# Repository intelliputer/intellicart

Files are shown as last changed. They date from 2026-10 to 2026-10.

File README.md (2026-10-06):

## Intellicart

Intellicart is a flash-cartridge project for the Mattel Intellivision. It loads Intellivision program images from a micro SD card and presents a small OLED/button interface for selecting and starting them on original hardware.

This repository brings together the hardware design, fabrication package, firmware, user documentation, and a small reverse-engineering workspace for experimenting with human--agent gameplay.

## Repository layout

| Path | Contents |
| --- | --- |
| [`board/project/`](board/project/) | KiCad schematic, PCB, project configuration, routing, and BOM files. |
| [`board/gerbers/`](board/gerbers/) | Generated fabrication deliverables: Gerbers, drill files, drill maps, and the Gerber job file. |
| [`development/arduino/`](development/arduino/) | Cartridge-controller firmware source. |
| [`development/checkers-disassembly/`](development/checkers-disassembly/) | CP1610 disassembly and analysis workspace for the bundled Checkers ROM. |
| [`manual/`](manual/) | Intellicart user manual as LaTeX source, diagram asset, and compiled PDF. |
| [`rom/`](rom/) | ROM images used for development and research. |
| [`images/`](images/) | Project imagery. |

## Hardware

The KiCad project is [`board/project/intellicart.kicad_pro`](board/project/intellicart.kicad_pro). For manufacturing, use the complete, matching output set in [`board/gerbers/`](board/gerbers/). KiCad is configured to place newly plotted outputs there (`../gerbers/` relative to the project directory).

## User manual

The editable source is [`manual/UserManual.tex`](manual/UserManual.tex). To rebuild the PDF:

```bash
cd manual
latexmk -pdf UserManual.tex
```

## Checkers human--agent gameplay research

[`rom/Checkers (1979) (Mattel).int`](rom/Checkers%20(1979)%20(Mattel).int) is an 8 KiB CP1610 ROM mapped at `$5000`--`$5FFF`. Its generated assembly listing lives in [`development/checkers-disassembly/checkers.asm`](development/checkers-disassembly/checkers.asm).

To regenerate that listing, place the SDK1600 repository adjacent to this one and run:

```bash
development/checkers-disassembly/build-disassembly.sh
```

The script builds a temporary native `dasm1600` executable from `../sdk1600/src/dasm/dasm1600.c`, so it does not add a compiled tool to this repository. The original ROM remains unmodified.

## Licensing and ROMs

The hardware and project files are provided under the repository's [license](LICENSE). ROM images may be subject to their own rights; use and distribute them only where you have the appropriate authorization.

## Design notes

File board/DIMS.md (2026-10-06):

## 44-pin edge connector 

The geometry of the edge connector is contained in the following.

| Feature | Dimension | Status / Notes |
|---|---:|---|
| Total electrical contacts | 44 | 22 contacts on each side of the cartridge PCB |
| Contacts per PCB side | 22 | One row of edge fingers per PCB surface |
| Contact pitch | 2.54 mm (0.100 in) | Cartridge contact spacing |
| Number of pitch intervals | 21 | 22 contacts create 21 intervals |
| First-to-last terminal center span | 53.34 mm (2.100 in) | 21 × 2.54 mm; agrees with the measured ~53.4 mm |
| Measured terminal-to-terminal span | ~53.4 mm | User measurement; presumably center-to-center |
| Overall contact-array width | Approximately 58 mm | Depends on terminal width and end margins |
| Cartridge PCB thickness | Approximately 1.6 mm (0.062 in) | Verify against the original cartridge PCB |
| Replacement connector solder-tail pitch | May be 3.96 mm (0.156 in) | Connector-specific; not the cartridge contact pitch |

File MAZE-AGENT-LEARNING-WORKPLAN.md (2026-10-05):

# Maze Agent Learning Workplan

## Purpose

Build agents that navigate finite mazes from local observations, and evaluate
them against a deterministic reference procedure. A completed run alone is not
evidence of a general solution: the input domain, available memory,
transition rules, and halting conditions must all be explicit.

This plan is based on Chapter 3, “An Algorithm for Finding Paths in a
Labyrinth,” in B. A. Trakhtenbrot’s *Algorithms and Automatic Computing
Machines*, and the accompanying project notes in
`references/trakhtenbrot-algorithms-and-automatic-computing-machines-notes.md`.

## 1. Define the Maze Contract

- Represent a maze as a finite, undirected graph of junctions and corridors.
- Record a cyclic ordering of exits at each junction, a start junction, and a
  target junction.
- Define observations, legal actions, available agent memory, terminal states,
  and a fixed tie-break convention. For example: choose the first unvisited
  exit clockwise from the corridor used to enter the junction.
- Convert procedural layouts, including Entombed-generated layouts, to this
  graph representation only after validating their entrances, exits, and
  connectivity.

**Deliverable:** a versioned `Maze` schema and deterministic, seeded map
generation.

## 2. Build the Reference Solver

Implement the Chapter 3 Theseus procedure:

- Mark corridors as untraversed (green), active path (yellow), or exhausted
  (red).
- At each junction, apply this priority order: target, loop, untraversed
  corridor, origin, then backtrack.
- Never traverse a red corridor.
- Emit a trace for every step: observation, controller state, selected
  corridor, marking change, position, and halt reason.

**Acceptance criteria:** the solver halts on every finite fixture, never
traverses a red corridor, and its yellow corridors always form the current
simple path from the start to the agent.

## 3. Create a Benchmark Curriculum

Introduce structural difficulty gradually:

1. Trees and single-route mazes.
2. Dead ends and unreachable targets.
3. Loops and several routes to the target.
4. Larger maps with varying cyclic exit order.
5. Held-out procedural and Entombed-derived layouts.

For each benchmark, preserve the seed, graph, reference trace, reachability
result, path length, corridor-traversal count, and expected halt reason.

## 4. Separate Learning Tracks

Keep three experiments distinct:

- **Imitation learning:** reproduce the reference controller from local
  observations and memory.
- **Reinforcement learning:** learn from reward; label this as learned and
  potentially stochastic behavior rather than a deterministic algorithm.
- **Memory ablations:** compare reactive agents, bounded recurrent memory, and
  agents with explicit corridor-marking memory.

This identifies which memory model is necessary, instead of measuring only
whether an agent eventually succeeds.

## 5. Evaluate Behavior, Not Only Completion

Measure:

- Reachability accuracy and false “unreachable” outcomes.
- Steps and corridor traversals against the reference solver.
- Invalid actions and red-corridor violations.
- Repeatability for an identical maze and seed.
- Generalization to unseen sizes, topologies, and corridor orderings.
- Trace agreement with the reference policy.

Every failure should retain a replayable trace.

## 6. Add Visual Inspection

Extend the existing maze display with:

- A junction-and-corridor graph view.
- Green, yellow, and red corridor states.
- Agent and target positions.
- Step, play, pause, and reset controls.
- Reference-versus-agent trace replay and export.

The current graphical renderer is a useful map-display starting point; the
next display should expose search state as well.

## 7. Milestones

| Milestone | Outcome |
| --- | --- |
| M1 | Maze schema, graph validator, and deterministic fixtures |
| M2 | Chapter 3 reference solver, traces, and invariant tests |
| M3 | Dataset generator and benchmark manifests |
| M4 | Imitation baseline and memory ablations |
| M5 | Reinforcement-learning baseline, held-out evaluation, and replay UI |
| M6 | Results report describing generalization, failures, and evidence |

## Guardrail

The book’s standard should remain the project standard: call a procedure an
algorithm only when its allowed inputs, deterministic transition rules,
representation or memory, and termination conditions are specified. Use the
learned-agent experiments to test behavior against that specification, not to
replace it.

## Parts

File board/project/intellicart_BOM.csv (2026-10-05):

Column1 | Column2 | Column3 | Column4 | Column5 | Column6 | Column7
Component Count: | 22
Individual Components:
Item | Qty | Reference(s) | Value | LibPart | Footprint | Datasheet
 |  | C1 | 100nF | Device:C | Capacitor_THT:C_Disc_D3.8mm_W2.6mm_P2.50mm | ~
 |  | C2 | 100nF | Device:C | Capacitor_THT:C_Disc_D3.8mm_W2.6mm_P2.50mm | ~
 |  | C3 | 100nF | Device:C | Capacitor_THT:C_Disc_D3.8mm_W2.6mm_P2.50mm | ~
 |  | C4 | 100nF | Device:C | Capacitor_THT:C_Disc_D3.8mm_W2.6mm_P2.50mm | ~
 |  | D1 | LED | Device:LED | LED_THT:LED_D3.0mm | ~
 |  | D2 | LED | Device:LED | LED_THT:LED_D3.0mm | ~
 |  | J2 | Oled 0.91" female | Connector:Conn_01x04_Male | Connector_PinHeader_2.54mm:PinHeader_1x04_P2.54mm_Vertical | ~
 |  | R1 | R220 | Device:R | Resistor_THT:R_Axial_DIN0204_L3.6mm_D1.6mm_P7.62mm_Horizontal | ~
 |  | R2 | R220 | Device:R | Resistor_THT:R_Axial_DIN0204_L3.6mm_D1.6mm_P7.62mm_Horizontal | ~
 |  | R3 | 1K | Device:R | Resistor_THT:R_Axial_DIN0204_L3.6mm_D1.6mm_P7.62mm_Horizontal | ~
 |  | R4 | 1K | Device:R | Resistor_THT:R_Axial_DIN0204_L3.6mm_D1.6mm_P7.62mm_Horizontal | ~
 |  | R5 | 1K | Device:R | Resistor_THT:R_Axial_DIN0204_L3.6mm_D1.6mm_P7.62mm_Horizontal | ~
 |  | R6 | 4K7 | Device:R | Resistor_THT:R_Axial_DIN0204_L3.6mm_D1.6mm_P7.62mm_Horizontal | ~
 |  | SW1 | SW_Push | Switch:SW_Push | Button_Switch_THT:SW_PUSH_6mm | ~
 |  | SW2 | SW_Push | Switch:SW_Push | Button_Switch_THT:SW_PUSH_6mm | ~
 |  | SW3 | SW_Push | Switch:SW_Push | Button_Switch_THT:SW_PUSH_6mm | ~
 |  | U1 | 74LVC245 | 74xx:74LS245 | Package_DIP:DIP-20_W7.62mm_Socket | http://www.ti.com/lit/gpn/sn74LS245
 |  | U2 | 74LVC245 | 74xx:74LS245 | Package_DIP:DIP-20_W7.62mm_Socket | http://www.ti.com/lit/gpn/sn74LS245
 |  | U3 | 74LVC245 | 74xx:74LS245 | Package_DIP:DIP-20_W7.62mm_Socket | http://www.ti.com/lit/gpn/sn74LS245
 |  | U4 | Teensy4.1 | teensy:Teensy4.1 | Teensy:Teensy41
 |  | U5 | 74LVC245 | 74xx:74LS245 | Package_DIP:DIP-20_W7.62mm_Socket | http://www.ti.com/lit/gpn/sn74LS245
Collated Components:
Item | Qty | Reference(s) | Value | LibPart | Footprint | Datasheet
1 | 4 | C1, C2, C3, C4 | 100nF | Device:C | Capacitor_THT:C_Disc_D3.8mm_W2.6mm_P2.50mm | ~
2 | 2 | D1, D2 | LED | Device:LED | LED_THT:LED_D3.0mm | ~
3 | 1 | J1 | 2x22 card edge connector | Evan's misc parts:2x22 card edge connector | Evan's misc parts:edge mounted 44 pin card edge connector (2x22 pin) | ~
4 | 1 | J2 | Oled 0.91" female | Connector:Conn_01x04_Male | Connector_PinHeader_2.54mm:PinHeader_1x04_P2.54mm_Vertical | ~
5 | 2 | R1, R2 | R220 | Device:R | Resistor_THT:R_Axial_DIN0204_L3.6mm_D1.6mm_P7.62mm_Horizontal | ~
6 | 3 | R3, R4, R5 | 1K | Device:R | Resistor_THT:R_Axial_DIN0204_L3.6mm_D1.6mm_P7.62mm_Horizontal | ~
7 | 1 | R6 | 4K7 | Device:R | Resistor_THT:R_Axial_DIN0204_L3.6mm_D1.6mm_P7.62mm_Horizontal | ~
8 | 3 | SW1, SW2, SW3 | SW_Push | Switch:SW_Push | Button_Switch_THT:SW_PUSH_6mm | ~
9 | 4 | U1, U2, U3, U5 | 74LVC245 | 74xx:74LS245 | Package_DIP:DIP-20_W7.62mm_Socket | http://www.ti.com/lit/gpn/sn74LS245
10 | 1 | U4 | Teensy4.1 | teensy:Teensy4.1 | Teensy:Teensy41

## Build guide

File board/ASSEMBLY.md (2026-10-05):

# Intellicart board assembly

This is a practical through-hole assembly and bring-up sequence for the
Intellicart PCB. It follows the construction order shown in the archived
reference build, while using the references and values from this repository's
[`project/intellicart_BOM.csv`](project/intellicart_BOM.csv). The reference
photos and setup screenshots are stored locally under
[`images/`](images/).

> Work with ESD precautions, a temperature-controlled soldering iron, and a
> current-limited USB supply where possible.  Do not insert an untested board
> into an Intellivision.

## Before soldering

1. Inspect the PCB for shorts, damaged edge contacts, or incomplete holes.
   Confirm that the cartridge-edge bevel and gold fingers, if ordered, are
   clean and undamaged.
2. Inventory the BOM and identify pin 1 on every DIP socket and IC.  Dry-fit
   the Teensy 4.1, the OLED header/display, buttons, LEDs, and the cartridge
   connector before committing solder.
3. If the Teensy or OLED may need to be removed later, use suitable machined
   headers/socket pins.  The illustrated build uses fine pins for these
   removable connections rather than permanently soldering the modules.

## Populate in height order

Install and inspect one group at a time.  Solder the shortest components
first, trim leads after each group, and check for bridges before continuing.

| Order | Fit | References / values | Notes |
| --- | --- | --- | --- |
| 1 | Resistors | R1–R2: 220 Ω; R3–R5: 1 kΩ; R6: 4.7 kΩ | Verify values before soldering. The reference build notes that R6 is not needed for normal operation; leave it fitted only if the schematic/firmware revision calls for it. |
| 2 | Decoupling capacitors | C1–C4: 100 nF | Fit close to their labelled positions. These ceramic capacitors are non-polar. |
| 3 | DIP sockets | U1, U2, U3, U5: 20-pin sockets | Align each notch with the PCB silkscreen. Solder opposite corner pins first, check that the socket is flat, then finish. Do **not** install the 74LVC245 devices yet. |
| 4 | OLED connector | J2: 1×4, 2.54 mm header/socket | Match the connector style to the OLED module and ensure its pin order agrees with the board silk/schematic. |
| 5 | Controls and indicators | SW1–SW3; D1–D2 | Buttons should sit square. Observe LED polarity: the long lead/anode must match the `+`/anode marking. |
| 6 | Cartridge interface | J1: 2×22 card-edge connector | Keep the connector exactly perpendicular to the PCB. Avoid contaminating the gold contacts with flux or solder. |
| 7 | Controller/module connections | U4: Teensy 4.1; OLED display | Fit removable headers or sockets if intended. Check all module pins are aligned before soldering. |
| 8 | Logic ICs | U1, U2, U3, U5: 74LVC245 | Only after all soldering and cleaning is complete, insert each IC into its socket with the notch/dot aligned to pin 1. |

## Inspection and electrical checks

Before connecting USB or the console:

1. Use magnification to inspect every joint, especially the Teensy headers,
   OLED header, DIP sockets, and cartridge-edge connector.
2. With a multimeter, check for a low-resistance short between the board's
   power and ground rails. Also check that adjacent edge contacts are not
   bridged.
3. Confirm each LED orientation and the pin-1 direction of every socket/IC.
4. Connect a micro-USB cable to the Teensy only. A pulsing red LED on the
   Teensy and a steady board LED are described as normal in the reference
   build; disconnect immediately if anything heats up or the supply limits.

## Program and prepare media

1. Install the Arduino IDE and the Teensy software add-on appropriate for the
   host operating system. Select the Teensy board and its USB serial port.
2. Open the RTO Cart firmware project referenced by the build article. Install
   its required `Adafruit_GFX` and `Adafruit_SSD1306` libraries, then compile
   and upload it to the Teensy. Use the firmware version that matches the
   installed board revision.
3. Format a microSD card and create `0.cfg` in its root with this default
   mapping from the illustrated guide:

   ```ini
   [mapping]
   $0000 - $1FFF = $5000 ; 8K to $5000 - $6FFF
   $2000 - $2FFF = $D000 ; 4K to $D000 - $DFFF
   $3000 - $3FFF = $F000 ; 4K to $F000 - $FFFF
   ```

4. Copy legally obtained cartridge images to the card as `.bin` files. A game
   that requires a non-default mapping needs a same-named `.cfg` file. The
   reference guide also notes that some `.int` images can be renamed `.bin`.
5. Insert the card, verify that the OLED lists the files, and test the buttons
   before the first console insertion.

## First console test

Power the console off, insert the cartridge gently and fully, then power on.
Choose a known-good small ROM from the OLED menu. If the display is blank,
buttons do not respond, or the console does not start the selected program,
power off first and recheck orientation, solder bridges, power continuity, and
the firmware/SD-card configuration.

## Illustrated reference build

The two retained photos show the PCB at the start of assembly and during
population. The rest of the photographed workflow is summarized below.

### Hardware build and test

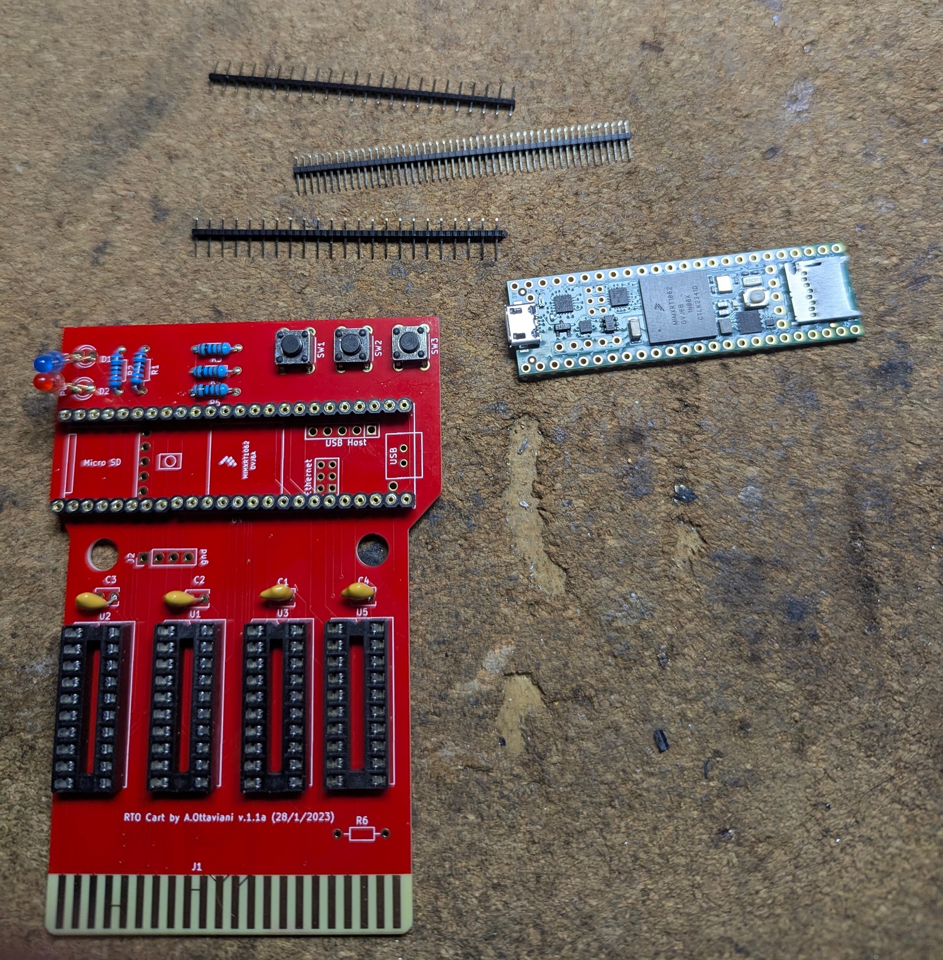
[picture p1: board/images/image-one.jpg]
Image one


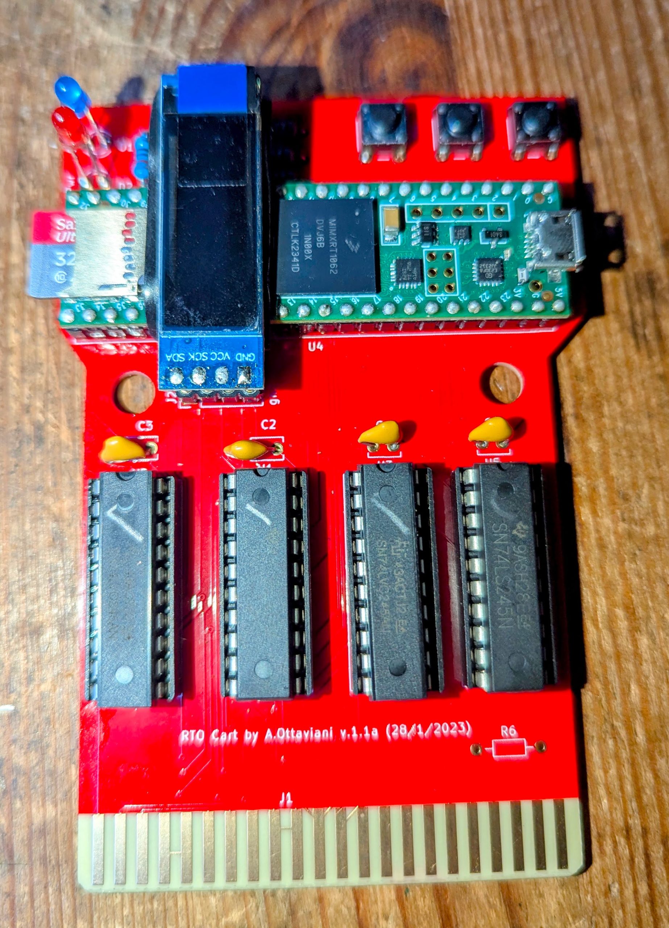
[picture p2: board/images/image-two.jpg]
Image two


After the pictured stages, complete the board by fitting the buttons, LEDs,
OLED connector, Teensy headers, and cartridge edge connector. Check the board
for bridges and correct orientation, then install the 74LVC245 devices in
their sockets. Connect the Teensy over USB, select the correct Teensy target
and serial port in the Arduino IDE, install the display libraries, and upload
the matching cartridge firmware. Finally, place `0.cfg` and the selected ROM
images on the microSD card, confirm that the OLED menu appears, and perform
the first console test as described above.

## Local references

- [`project/intellicart_BOM.csv`](project/intellicart_BOM.csv) — repository-specific references, quantities, and values.
- [`project/intellicart.kicad_sch`](project/intellicart.kicad_sch) — authoritative connectivity and orientation information for this PCB.
- `images/image-one.jpg` and `images/image-two.jpg` — retained reference build photos.

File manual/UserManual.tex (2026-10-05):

\documentclass[a4paper,11pt]{article}
\usepackage[margin=2cm]{geometry}
\usepackage[T1]{fontenc}
\usepackage[utf8]{inputenc}
\usepackage{lmodern}
\usepackage{graphicx}
\usepackage{enumitem}
\usepackage{hyperref}
\setlist{nosep}
\setlength{\parindent}{0pt}
\setlength{\parskip}{.65em}
\newcommand{\intellicart}{Intellicart}
\newcommand{\file}[1]{\texttt{#1}}

\title{INTELLICART CARTRIDGE\\USER MANUAL}
\author{Cartheur Research}
\date{}

\begin{document}
\maketitle

The hardware cartridge ``Intellivision \intellicart'' (henceforth referred to as Intellicart) allows Program/Game files to be loaded on an Intellivision console. These files are ``Cartridge Dumps'': transfers of programs contained in Intellivision-cartridge ROMs. Store the files on a micro SD card, insert it in the compartment on the left of the Intellicart, then insert the Intellicart into the console cartridge port.

\section*{Technical features}
\begin{itemize}
  \item Supported console: Mattel Intellivision.
  \item Compatible files: \file{.BIN} + \file{.CFG}.
  \item Reads files from a micro SD card; compatible media are 1--32~GB micro SD cards formatted FAT or FAT32.
  \item Compatible with PAL, NTSC, and SECAM Intellivision consoles.
  \item Files are searched and loaded using the three push buttons on the cartridge.
  \item Place titles in the micro SD root, or in folders in that root; subfolders cannot be used.
  \item Store the basic \file{0.cfg} configuration file in the root; see the appendix.
  \item Long names are supported up to 45 characters plus the file extension.
  \item The OLED displays folders and files. Two LEDs indicate cartridge operation.
  \item Power is supplied directly from the console cartridge port.
\end{itemize}

\section*{Important}
Make all electrical and mechanical connections or disconnections with equipment switched off and cables disconnected from mains outlets.

Clean the Intellicart only with antistatic cloths; do not use liquids. It contains electronic components and a PLA or ABS plastic case. Do not press the small OLED-display window: it is delicate and pressure can damage or dislodge it, damaging internal components. Do not disassemble the cartridge or attempt repairs; only qualified personnel should do so.

Do not spill liquids on the Intellicart. After an accidental spill, do not insert it into the console; if it is already inserted, immediately unplug the console. Dry and clean the Intellicart completely before connecting it.

The user is solely responsible for damage to people, animals, or property arising from use of the Intellicart cartridge. Cartheur Research, B.V., the hardware designer, manual author, and vendors are not responsible for such damage. Using the Intellicart Cartridge for Intellivision signifies agreement to these conditions.

\section*{Intellivision console connection}
Insert the cartridge directly into the console's right cartridge port, with the side containing the text and LEDs facing up.

\textit{Tip:} Place a stand or support base under the Intellicart so it remains rigid while the push buttons are pressed. This prevents the cartridge from flexing and avoids force on the Intellivision connector contacts. Flexing can create false contacts, malfunctions, or eventually damage the console connector or cartridge. This is advisable because the Intellicart's buttons are on the cartridge itself.

\section*{Using the Intellicart cartridge}
On a personal computer (these directions assume Windows), copy program files with \file{.BIN} and \file{.CFG} extensions to the micro SD card. You may create folders only in the root to sort files by genre, type, and so on; do not create subfolders. Files may be in the root or one root-level folder. A \file{.BIN} must always have a same-named \file{.CFG}, for example \file{Burgertime.bin} and \file{Burgertime.cfg}.

\textit{Note:} If only the \file{.BIN} file is transferred, Intellicart uses the default configuration \file{0.cfg}, which must be in the SD-card root. It may or may not be compatible with that \file{.BIN}. In general, \file{0.cfg} works with most, but not all, ROMs. If neither the associated configuration nor \file{0.cfg} is present, the Program/Game cannot run.

The \file{.BIN} contains the ROM dump; the \file{.CFG} tells the cartridge how its data areas are allocated in the Intellivision memory map. Without correct configuration data, Intellicart does not know where to place ROM contents and cannot start the program.

Some \file{.CFG} files contain ``Hacks'', such as infinite lives, longer stages, invulnerability, or a starting-stage selection. When Intellicart detects them, it asks whether to activate them. Press PB~2 to activate Hacks; press PB~1 or PB~3 to start the standard game. Emulator-oriented Hack configurations may not be fully compatible with the console and Intellicart.

\textit{Tip:} To retain alphabetical OLED order, keep all Programs/Games in a PC folder. Select all titles and folders, copy starting from the first alphabetically, and paste them onto the SD card. To add titles later, add them first to that PC folder, erase the SD-card contents, then transfer the complete folder again. Adding files directly to a populated SD card can make new titles appear first or among existing titles.

\section*{Naming files}
Although long names are supported, simplify them to avoid a title not being recognized. Avoid spaces where practical; use hyphens and underscores instead. Avoid dots, apostrophes, commas, exclamation/question marks, asterisks, and similar symbols. Keep names under 45 characters.

For example, reduce \file{Masters of the Universe-The Power of He-Man! (1983) (Mattel).bin} to \file{Masters\_o\_t\_Universe-T\_P\_o\_He-Man-(1983).bin}. You may retain original names if desired, provided they meet the length limit. Simplification is needed only if a title appears as a blank space while browsing the OLED.

Once the card is prepared, insert it in the Intellicart's left-side slot with its label facing up and contacts facing down. Insert the Intellicart in the console's right cartridge slot, then turn on the television/monitor and console.

\section*{Intellicart push-button functions}
\begin{center}
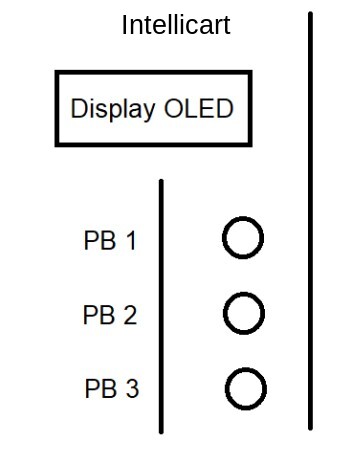
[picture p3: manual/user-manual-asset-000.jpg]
  
\end{center}

\subsection*{Before starting a ROM}
\begin{description}[style=nextline]
  \item[PB 1] Scroll titles and folders forward.
  \item[PB 2] Enter or exit a folder; start the selected file. To exit a folder, use PB~1 or PB~3 to show either \file{. . Kb:0} exit point, then press PB~2.
  \item[PB 3] Scroll titles and folders backward.
\end{description}

\subsection*{While a Program/Game is running}
\begin{description}[style=nextline]
  \item[PB 1] Reset the Intellivision. If the TV/monitor becomes black, the console's reset-line capacitor is defective; also press the console Reset button to restart the running program.
  \item[PB 2] Not used.
  \item[PB 3] Reset the Intellicart cartridge.
\end{description}

When powered on, the TV/monitor shows \texttt{Intellicart - Cart Please Select a Game}; the OLED shows \texttt{Press a Button on Intellicart}. Use PB~1 and PB~3 to select titles or folders. If the main screen does not appear and navigation does not work, the console's reset-line capacitor is defective. Press the Intellivision Reset button to activate Intellicart and show the main screen.

PB~2 enters a folder or starts a Program/Game. The OLED displays \file{filename.bin}, not the system-only \file{filename.cfg}, and shows ROM size in Kb beneath it. Pressing PB~2 loads the ROM and shows \texttt{Emulating ROM: filename.bin}. If the display remains black because of the defective capacitor, press the console Reset button to start the Program/Game.

Once started, control moves to the Intellivision gamepads. The console Reset button or Intellicart PB~1 restarts the Program/Game as if an original cartridge were inserted. PB~3 resets Intellicart and unloads the game; the OLED returns to \texttt{Press a button on Intellicart} and the TV/monitor goes black. With the defective capacitor, press the console Reset button after unloading before selecting another Program/Game.

\section*{Intellivision file formats}
The three common cartridge-dump formats are \file{filename.BIN}, \file{filename.INT}, and \file{filename.ROM}.
\begin{enumerate}
  \item \file{filename.BIN} is the classic binary ROM dump and requires \file{filename.CFG}.
  \item \file{filename.INT} is the same binary format with a different extension, originally used by emulators to avoid Windows \file{.BIN} associations. It also requires \file{filename.CFG}.
  \item \file{filename.ROM} includes both binary and configuration data, so it does not need a separate configuration file.
\end{enumerate}
Intellicart supports only \file{.BIN}; \file{.INT} and \file{.ROM} will not appear on the OLED and are not handled directly.

\subsection*{\file{filename.INT}}
Rename the extension from \file{.INT} to \file{.BIN}, for example \file{burgertime.int} becomes \file{burgertime.bin}, then treat it as an ordinary BIN file.

\subsection*{\file{filename.ROM}}
A ROM file embeds the corresponding BIN and CFG data. Extract them using \file{rom2bin.exe}, available in the \texttt{bin/} directory of the jzIntv SDK at \url{http://spatula-city.org/~im14u2c/intv/}. Copy \file{rom2bin.exe} and the files to convert into one folder, then drag \file{namefile.rom} onto \file{rom2bin.exe}. This produces \file{namefile.bin} and \file{namefile.cfg}, which are compatible with Intellicart.

\section*{If a Program/Game does not run}
\begin{enumerate}
  \item BIN and CFG names differ. Rename the CFG to match the BIN exactly.
  \item Files are in a subfolder. Move them to the SD-card root or a root-level folder, then delete the subfolder.
  \item A ROM was converted incorrectly. Repeat the conversion.
  \item The BIN is not an Intellivision binary ROM. It is unusable.
  \item The BIN or CFG is corrupt. It is unusable.
  \item The CFG is incorrect or emulator-only. Correct and edit the CFG.
\end{enumerate}

\section*{Correcting and editing CFG files}
CFG files originated for Intellivision emulators and define ROM/RAM memory allocation. Emulator evolution has added parameters, so multiple CFG variants may exist for one game. Intellicart recognizes basic mappings. For example, the first version below works, while the second must have its \texttt{ECS} line removed.
\begin{verbatim}
[mapping]                 [mapping]
$0000 - $1FFF = $5000     ECS
                          $0000 - $1FFF = $5000
\end{verbatim}

Example standard configuration:
\begin{verbatim}
[mapping]
$0000 - $1FFF = $5000 ; 8K to $5000 - $6FFF
$2000 - $2FFF = $D000 ; 4K to $D000 - $DFFF
$3000 - $3FFF = $F000 ; 4K to $F000 - $FFFF
\end{verbatim}

A Hack configuration can add sections after the mapping:
\begin{verbatim}
[mapping]
$0000 - $1FFF = $5000
[memattr]
$D000 - $DFFF = ROM 16
$F000 - $FFFF = ROM 16
[macro]
p 633a 34 ; Infinite peppers (both players)
p 51f9 34 ; Infinite lives (both players)
\end{verbatim}

No text or parameters may occur before \file{[mapping]}; delete any that do. Complex emulator CFGs may contain \file{[vars]} metadata before mapping and must be trimmed so that \file{[mapping]} begins the file. Retain the mapping, memory attributes, and desired macro lines.

To edit \file{filename.cfg} on Windows, temporarily add \file{.TXT}, producing \file{filename.cfg.txt}; accept Windows' extension-change warning. Open it in a text editor such as Notepad, edit and save it, then remove the added \file{.TXT} extension before testing.

\section*{Appendix: basic \file{0.cfg}}
Find \file{0.cfg} online or create it in a text editor with the following contents, then save it as \file{0.cfg}:
\begin{verbatim}
[mapping]
$0000 - $1FFF = $5000 ; 8K to $5000 - $6FFF
$2000 - $2FFF = $D000 ; 4K to $D000 - $DFFF
$3000 - $3FFF = $F000 ; 4K to $F000 - $FFFF
\end{verbatim}

\end{document}

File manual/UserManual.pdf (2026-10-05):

## INTELLICART CARTRIDGE USER MANUAL

Cartheur Research

The hardware cartridge “Intellivision Intellicart” (henceforth referred to as Intellicart) allows Program/Game files to be loaded on an Intellivision console. These files are “Cartridge Dumps”: transfers of programs contained in Intellivision-cartridge ROMs. Store the files on a micro SD card, insert it in the compartment on the left of the Intellicart, then insert the Intellicart into the console cartridge port.

### Technical features

- Supported console: Mattel Intellivision.
- Compatible files: .BIN + .CFG.
- Reads files from a micro SD card; compatible media are 1–32 GB micro SD cards formatted FAT or FAT32.
- Compatible with PAL, NTSC, and SECAM Intellivision consoles.
- Files are searched and loaded using the three push buttons on the cartridge.
- Place titles in the micro SD root, or in folders in that root; subfolders cannot be used.
- Store the basic 0.cfg configuration file in the root; see the appendix.
- Long names are supported up to 45 characters plus the file extension.
- The OLED displays folders and files. Two LEDs indicate cartridge operation.
- Power is supplied directly from the console cartridge port.

### Important

Make all electrical and mechanical connections or disconnections with equipment switched off and cables disconnected from mains outlets.

Clean the Intellicart only with antistatic cloths; do not use liquids. It contains electronic components and a PLA or ABS plastic case. Do not press the small OLED-display window: it is delicate and pressure can damage or dislodge it, damaging internal components. Do not disassemble the cartridge or attempt repairs; only qualified personnel should do so.

Do not spill liquids on the Intellicart. After an accidental spill, do not insert it into the console; if it is already inserted, immediately unplug the console. Dry and clean the Intellicart completely before connecting it.

The user is solely responsible for damage to people, animals, or property arising from use of the Intellicart cartridge. Cartheur Research, B.V., the hardware designer, manual author, and vendors are not responsible for such damage. Using the Intellicart Cartridge for Intellivision signifies agreement to these conditions.

### Intellivision console connection

Insert the cartridge directly into the console’s right cartridge port, with the side containing the text and LEDs facing up.

Tip: Place a stand or support base under the Intellicart so it remains rigid while the push buttons are pressed. This prevents the cartridge from flexing and avoids force on the Intellivision connector contacts. Flexing can create false contacts, malfunctions, or eventually damage the console connector or cartridge. This is advisable because the Intellicart’s buttons are on the cartridge itself.

### Using the Intellicart cartridge

On a personal computer (these directions assume Windows), copy program files with .BIN and .CFG extensions to the micro SD card. You may create folders only in the root to sort files by genre, type, and so on; do not create subfolders. Files may be in the root or one root-level folder. A .BIN must always have a same-named .CFG, for example Burgertime.bin and Burgertime.cfg.

Note: If only the .BIN file is transferred, Intellicart uses the default configuration 0.cfg, which must be in the SD-card root. It may or may not be compatible with that .BIN. In general, 0.cfg works with most, but not all, ROMs. If neither the associated configuration nor 0.cfg is present, the Program/Game cannot run.

The .BIN contains the ROM dump; the .CFG tells the cartridge how its data areas are allocated in the Intellivision memory map. Without correct configuration data, Intellicart does not know where to place ROM contents and cannot start the program.

Some .CFG files contain “Hacks”, such as infinite lives, longer stages, invulnerability, or a starting-stage selection. When Intellicart detects them, it asks whether to activate them. Press PB 2 to activate Hacks; press PB 1 or PB 3 to start the standard game. Emulator-oriented Hack configurations may not be fully compatible with the console and Intellicart.

Tip: To retain alphabetical OLED order, keep all Programs/Games in a PC folder. Select all titles and folders, copy starting from the first alphabetically, and paste them onto the SD card. To add titles later, add them first to that PC folder, erase the SD-card contents, then transfer the complete folder again. Adding files directly to a populated SD card can make new titles appear first or among existing titles.

### Naming files

Although long names are supported, simplify them to avoid a title not being recognized. Avoid spaces where practical; use hyphens and underscores instead. Avoid dots, apostrophes, commas, exclamation/question marks, asterisks, and similar symbols. Keep names under 45 characters.

For example, reduce Masters of the Universe-The Power of He-Man! (1983) (Mattel).bin to Masters_o_t_Universe-T_P_o_He-Man-(1983).bin. You may retain original names if desired, provided they meet the length limit. Simplification is needed only if a title appears as a blank space while browsing the OLED.

Once the card is prepared, insert it in the Intellicart’s left-side slot with its label facing up and contacts facing down. Insert the Intellicart in the console’s right cartridge slot, then turn on the television/monitor and console.

### Intellicart push-button functions

Before starting a ROM

PB 1

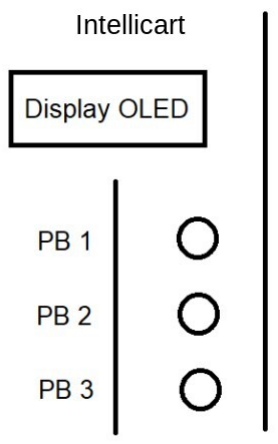
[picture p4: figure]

Scroll titles and folders forward.
PB 2
Enter or exit a folder; start the selected file. To exit a folder, use PB 1 or PB 3 to show either
. | . | Kb:0 exit point, then press PB 2.
PB 3
Scroll titles and folders backward.

While a Program/Game is running

PB 1
Reset the Intellivision. If the TV/monitor becomes black, the console’s reset-line capacitor is defective; also press the console Reset button to restart the running program.
PB 2
Not used.
PB 3
Reset the Intellicart cartridge.

When powered on, the TV/monitor shows Intellicart - Cart Please Select a Game; the OLED shows Press a Button on Intellicart. Use PB 1 and PB 3 to select titles or folders. If the main screen does not appear and navigation does not work, the console’s reset-line capacitor is defective. Press the Intellivision Reset button to activate Intellicart and show the main screen.

PB 2 enters a folder or starts a Program/Game. The OLED displays filename.bin, not the systemonly filename.cfg, and shows ROM size in Kb beneath it. Pressing PB 2 loads the ROM and shows Emulating ROM: filename.bin. If the display remains black because of the defective capacitor, press the console Reset button to start the Program/Game.

Once started, control moves to the Intellivision gamepads. The console Reset button or Intellicart PB 1 restarts the Program/Game as if an original cartridge were inserted. PB 3 resets Intellicart and unloads the game; the OLED returns to Press a button on Intellicart and the TV/monitor goes black. With the defective capacitor, press the console Reset button after unloading before selecting another Program/Game.

### Intellivision file formats

The three common cartridge-dump formats are filename.BIN, filename.INT, and filename.ROM.

1. filename.BIN is the classic binary ROM dump and requires filename.CFG.
2. filename.INT is the same binary format with a different extension, originally used by emulators to avoid Windows .BIN associations. It also requires filename.CFG.
3. filename.ROM includes both binary and configuration data, so it does not need a separate configuration file.

Intellicart supports only .BIN; .INT and .ROM will not appear on the OLED and are not handled directly.

filename.INT

Rename the extension from .INT to .BIN, for example burgertime.int becomes burgertime.bin, then treat it as an ordinary BIN file.

filename.ROM

A ROM file embeds the corresponding BIN and CFG data. Extract them using rom2bin.exe, available in the bin/ directory of the jzIntv SDK at http://spatula-city.org/~im14u2c/intv/. Copy rom2bin.exe and the files to convert into one folder, then drag namefile.rom onto rom2bin.exe. This produces namefile.bin and namefile.cfg, which are compatible with Intellicart.

### If a Program/Game does not run

1. BIN and CFG names differ. Rename the CFG to match the BIN exactly.
2. Files are in a subfolder. Move them to the SD-card root or a root-level folder, then delete the subfolder.
3. A ROM was converted incorrectly. Repeat the conversion.
4. The BIN is not an Intellivision binary ROM. It is unusable.
5. The BIN or CFG is corrupt. It is unusable.
6. The CFG is incorrect or emulator-only. Correct and edit the CFG.

### Correcting and editing CFG files

CFG files originated for Intellivision emulators and define ROM/RAM memory allocation. Emulator evolution has added parameters, so multiple CFG variants may exist for one game. Intellicart recognizes basic mappings. For example, the first version below works, while the second must have its ECS line removed.

[mapping] | [mapping]
$0000 - $1FFF = $5000 | ECS
| $0000 - $1FFF = $5000

Example standard configuration:

[mapping]
$0000 - $1FFF = $5000 ; 8K to $5000 - $6FFF $2000 - $2FFF = $D000 ; 4K to $D000 - $DFFF $3000 - $3FFF = $F000 ; 4K to $F000 - $FFFF

A Hack configuration can add sections after the mapping:

[mapping]
$0000 - $1FFF = $5000
[memattr]
$D000 - $DFFF = ROM 16
$F000 - $FFFF = ROM 16
[macro]
p 633a 34 ; Infinite peppers (both players)
p 51f9 34 ; Infinite lives (both players)

No text or parameters may occur before [mapping]; delete any that do. Complex emulator CFGs may contain [vars] metadata before mapping and must be trimmed so that [mapping] begins the file. Retain the mapping, memory attributes, and desired macro lines.

To edit filename.cfg on Windows, temporarily add .TXT, producing filename.cfg.txt; accept Windows’ extension-change warning. Open it in a text editor such as Notepad, edit and save it, then remove the added .TXT extension before testing.

### Appendix: basic 0.cfg

Find 0.cfg online or create it in a text editor with the following contents, then save it as 0.cfg:

[mapping]
$0000 - $1FFF = $5000 ; 8K to $5000 - $6FFF
$2000 - $2FFF = $D000 ; 4K to $D000 - $DFFF $3000 - $3FFF = $F000 ; 4K to $F000 - $FFFF

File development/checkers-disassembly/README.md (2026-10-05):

# Checkers ROM analysis workspace

This directory contains the CP1610 disassembly of the original Checkers ROM used for the human--agent gameplay prototype.

## Input

- ROM: [`../../rom/Checkers (1979) (Mattel).int`](../../rom/Checkers%20(1979)%20(Mattel).int)
- SHA-256: `07d5180de07d49260b45aa2795eef2479743af842496646bbef6bdd81f9a8ae9`
- Size: 8,192 bytes (4,096 big-endian 16-bit words)
- Cartridge mapping: `$5000`--`$5FFF`
- CPU: General Instrument CP1610

## Contents

- `checkers.asm` is the generated CP1610 assembly listing. The cartridge header at `$5000`--`$504F` is explicitly emitted as `DECLE` data; executable code begins at `$5050`.
- `checkers.sym` supplies the mapping and data boundary to the disassembler.
- `build-disassembly.sh` rebuilds the listing from the ROM using the adjacent `../sdk1600` repository.
- `extract-words.sh` produces a lossless, address-labelled word listing for manual annotation and verification.

The listing is mechanically generated and preserves the ROM words in comments. Labels are auto-generated by the disassembler, so semantic names for routines, board state, and human--agent hooks remain a separate annotation pass. The ROM itself remains unchanged.

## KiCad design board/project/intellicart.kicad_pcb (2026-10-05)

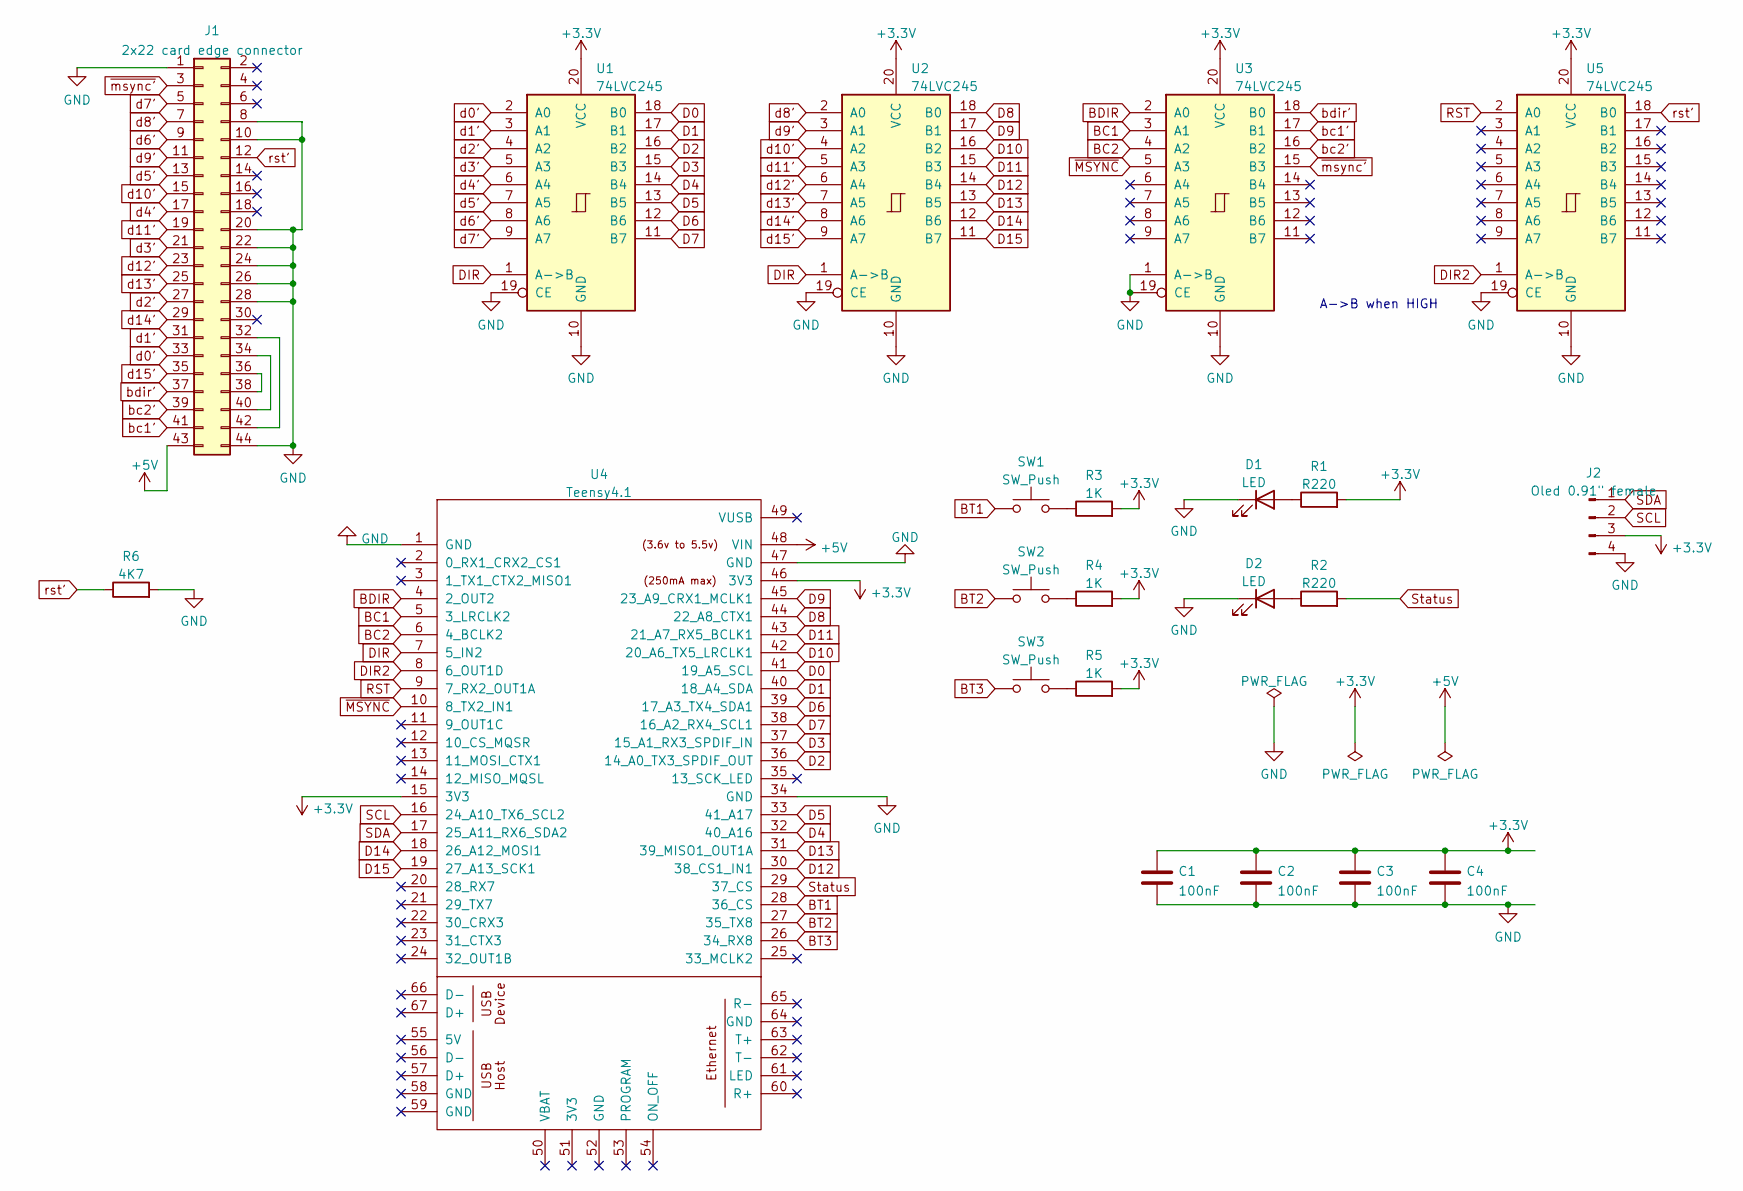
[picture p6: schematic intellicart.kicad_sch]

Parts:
C1, C2, C3, C4: 100nF; C_Disc_D3.8mm_W2.6mm_P2.50mm
D1, D2: LED; LED_D3.0mm
J1: 2x22 card edge connector; edge mounted 44 pin card edge connector (2x22 pin)
J2: Oled 0.91" female; PinHeader_1x04_P2.54mm_Vertical
R1, R2: R220; R_Axial_DIN0204_L3.6mm_D1.6mm_P7.62mm_Horizontal
R3, R4, R5: 1K; R_Axial_DIN0204_L3.6mm_D1.6mm_P7.62mm_Horizontal
R6: 4K7; R_Axial_DIN0204_L3.6mm_D1.6mm_P7.62mm_Horizontal
SW1, SW2, SW3: SW_Push; SW_PUSH_6mm
U1, U2, U3, U5: 74LVC245; DIP-20_W7.62mm_Socket
U4: Teensy4.1; Teensy41

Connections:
+3.3V: C1.1, C2.1, C3.1, C4.1, J2.3, R1.2, R3.2, R4.2, R5.2, U1.20 (VCC), U2.20 (VCC), U3.20 (VCC), U4.15 (3V3), U4.46 (3V3), U5.20 (VCC)
+5V: J1.43, U4.48 (VIN)
BC1: U3.3 (A1), U4.5 (3_LRCLK2)
BC2: U3.4 (A2), U4.6 (4_BCLK2)
BDIR: U3.2 (A0), U4.4 (2_OUT2)
BT1: SW1.1, U4.28 (36_CS)
BT2: SW2.1, U4.27 (35_TX8)
BT3: SW3.1, U4.26 (34_RX8)
D0: U1.18 (B0), U4.41 (19_A5_SCL)
D1: U1.17 (B1), U4.40 (18_A4_SDA)
D2: U1.16 (B2), U4.36 (14_A0_TX3_SPDIF_OUT)
D3: U1.15 (B3), U4.37 (15_A1_RX3_SPDIF_IN)
D4: U1.14 (B4), U4.32 (40_A16)
D5: U1.13 (B5), U4.33 (41_A17)
D6: U1.12 (B6), U4.39 (17_A3_TX4_SDA1)
D7: U1.11 (B7), U4.38 (16_A2_RX4_SCL1)
D8: U2.18 (B0), U4.44 (22_A8_CTX1)
D9: U2.17 (B1), U4.45 (23_A9_CRX1_MCLK1)
D10: U2.16 (B2), U4.42 (20_A6_TX5_LRCLK1)
D11: U2.15 (B3), U4.43 (21_A7_RX5_BCLK1)
D12: U2.14 (B4), U4.30 (38_CS1_IN1)
D13: U2.13 (B5), U4.31 (39_MISO1_OUT1A)
D14: U2.12 (B6), U4.18 (26_A12_MOSI1)
D15: U2.11 (B7), U4.19 (27_A13_SCK1)
DIR: U1.1 (A->B), U2.1 (A->B), U4.7 (5_IN2)
DIR2: U4.8 (6_OUT1D), U5.1 (A->B)
GND: C1.2, C2.2, C3.2, C4.2, D1.1 (K), D2.1 (K), J1.1, J1.8, J1.10, J1.20, J1.22, J1.24, J1.26, J1.28, J1.44, J2.4, R6.2, U1.10 (GND), U1.19 (CE), U2.10 (GND), U2.19 (CE), U3.1 (A->B), U3.10 (GND), U3.19 (CE), U4.1 (GND), U4.34 (GND), U4.47 (GND), U5.10 (GND), U5.19 (CE)
unnamed: D1.2 (A), R1.1
unnamed: D2.2 (A), R2.1
unnamed: J1.32, J1.42
unnamed: J1.34, J1.40
unnamed: J1.36, J1.38
unnamed: R3.1, SW1.2
unnamed: R4.1, SW2.2
unnamed: R5.1, SW3.2
RST: U4.9 (7_RX2_OUT1A), U5.2 (A0)
SCL: J2.2, U4.16 (24_A10_TX6_SCL2)
SDA: J2.1, U4.17 (25_A11_RX6_SDA2)
Status: R2.2, U4.29 (37_CS)
bc1': J1.41, U3.17 (B1)
bc2': J1.39, U3.16 (B2)
bdir': J1.37, U3.18 (B0)
d0': J1.33, U1.2 (A0)
d1': J1.31, U1.3 (A1)
d2': J1.27, U1.4 (A2)
d3': J1.21, U1.5 (A3)
d4': J1.17, U1.6 (A4)
d5': J1.13, U1.7 (A5)
d6': J1.9, U1.8 (A6)
d7': J1.5, U1.9 (A7)
d8': J1.7, U2.2 (A0)
d9': J1.11, U2.3 (A1)
d10': J1.15, U2.4 (A2)
d11': J1.19, U2.5 (A3)
d12': J1.23, U2.6 (A4)
d13': J1.25, U2.7 (A5)
d14': J1.29, U2.8 (A6)
d15': J1.35, U2.9 (A7)
rst': J1.12, R6.1, U5.18 (B0)
~MSYNC: U3.5 (A3), U4.10 (8_TX2_IN1)
~msync': J1.3, U3.15 (B3)

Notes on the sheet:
A->B when HIGH

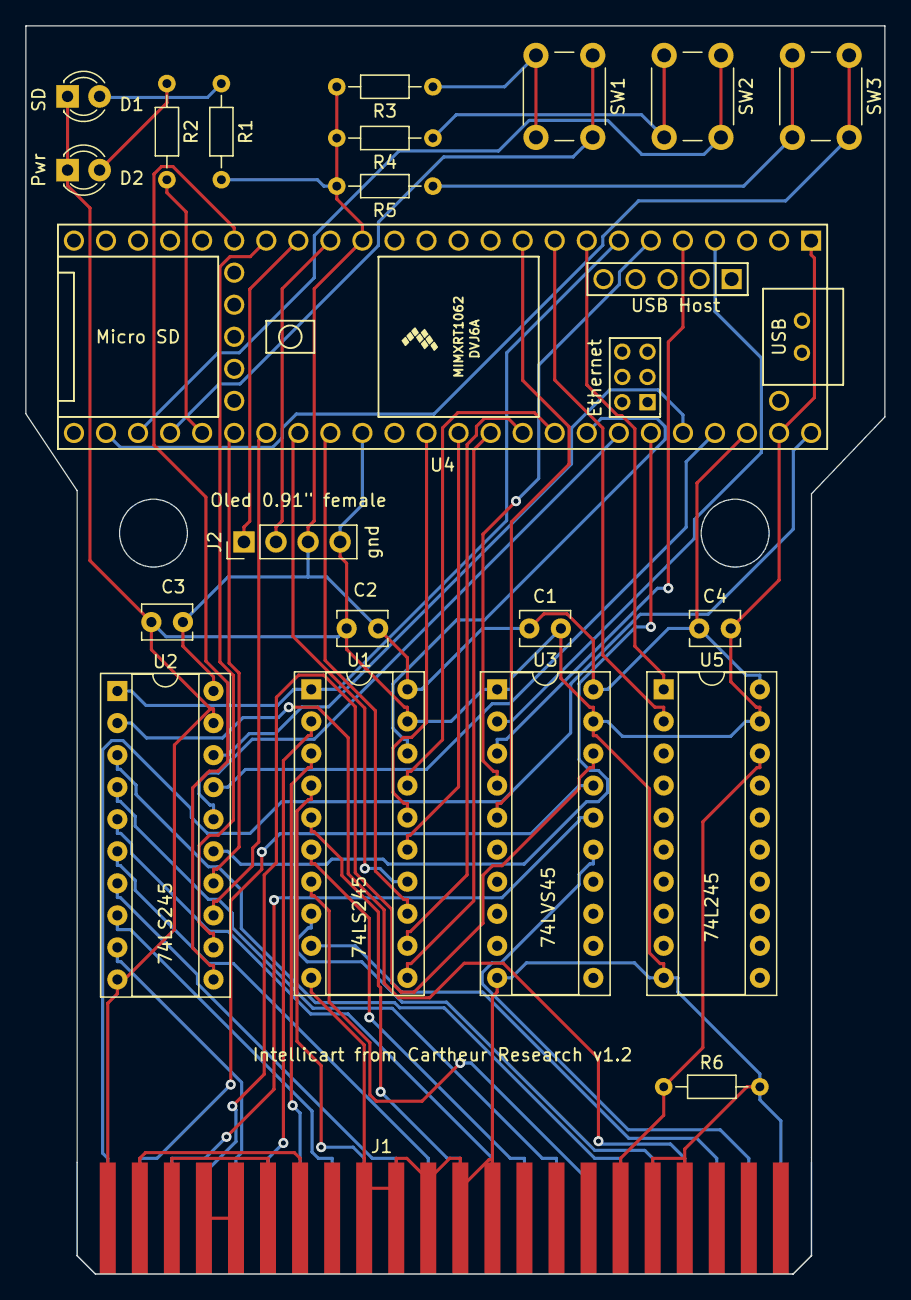
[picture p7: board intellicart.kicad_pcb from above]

Board: 2 copper layers, 68.1 x 98.9 mm, 22 parts (0 on the bottom side), 61 nets.

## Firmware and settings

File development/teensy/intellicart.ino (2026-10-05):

/*
 * Intellicart firmware for Teensy 4.1.
 */

// OLED display
#include <SPI.h>
#include <Wire.h>               // SCL pin 19, SDA pin 18 SCL2 25, SDA2 24

#include <Adafruit_GFX.h>
#include <Adafruit_SSD1306.h>

constexpr uint8_t SCREEN_WIDTH = 128;
constexpr uint8_t SCREEN_HEIGHT = 32;

// Declaration for an SSD1306 display connected to I2C (SDA, SCL pins)
// The pins for I2C are defined by the Wire-library.
// On an arduino UNO:       A4(SDA), A5(SCL)
// On an arduino MEGA 2560: 20(SDA), 21(SCL)
// On an arduino LEONARDO:   2(SDA),  3(SCL), ...
constexpr int8_t OLED_RESET = -1;
constexpr uint8_t SCREEN_ADDRESS = 0x3C;
Adafruit_SSD1306 display(SCREEN_WIDTH, SCREEN_HEIGHT, &Wire2, OLED_RESET);

 // include the SD library:
//-#include <SD.h>

#include "splash.h"
#include <FS.h>
#include <SdFat.h>

// SDCARD_SS_PIN is defined for the built-in SD on some boards.
#ifndef SDCARD_SS_PIN
const uint8_t SD_CS_PIN = SS;
#else  // SDCARD_SS_PIN
// Assume built-in SD is used.
const uint8_t SD_CS_PIN = SDCARD_SS_PIN;
#endif  // SDCARD_SS_PIN


// change this to match your SD shield or module;
// Teensy 3.5 & 3.6 & 4.1 on-board: BUILTIN_SDCARD
//const int chipSelect = BUILTIN_SDCARD;


// Try max SPI clock for an SD. Reduce SPI_CLOCK if errors occur.
#define SPI_CLOCK SD_SCK_MHZ(50)

// Try to select the best SD card configuration.
#if HAS_SDIO_CLASS
#define SD_CONFIG SdioConfig(FIFO_SDIO)
#elif  ENABLE_DEDICATED_SPI
#define SD_CONFIG SdSpiConfig(SD_CS_PIN, DEDICATED_SPI, SPI_CLOCK)
#else  // HAS_SDIO_CLASS
#define SD_CONFIG SdSpiConfig(SD_CS_PIN, SHARED_SPI, SPI_CLOCK)
#endif  // HAS_SDIO_CLASS

// set up variables using the SD utility library functions:
SdFs sd;
FsFile root;
FsFile entry;
FsFile mapfile;
//-File root;
//-File entry;
//-File mapfile;

// here is one continuous block of 16 bits
// should be able to read like this
// uint16_t addr= (GPIO6_DR & 0xFF00) / 256;

// Teensy pin usage definitions
#define D0_PIN    19 //GPIO6_16
#define D1_PIN    18 //GPIO6_17
#define D2_PIN    14 //GPIO6_18
#define D3_PIN    15 //GPIO6_19
#define D4_PIN    40 //GPIO6_20
#define D5_PIN    41 //GPIO6_21
#define D6_PIN    17 //GPIO6_22
#define D7_PIN    16 //GPIO6_23
#define D8_PIN    22 //GPIO6_24
#define D9_PIN    23 //GPIO6_25
#define D10_PIN   20 //GPIO6_26
#define D11_PIN   21 //GPIO6_27
#define D12_PIN   38 //GPIO6_28
#define D13_PIN   39 //GPIO6_29
#define D14_PIN   26 //GPIO6_30
#define D15_PIN   27 //GPIO6_31

int D_PIN[] ={19,18,14,15,40,41,17,16,22,23,20,21,38,39,26,27};

#define BDIR_PIN  2 //GPIO4_4
#define BC1_PIN   3 //GPIO4_5
#define BC2_PIN   4 //GPIO4_6
#define DIR_PIN   5 //GPIO4_8 - TO PIN 1 LVC245, HIGH= A->B (INPUT 5V TO 3.3V) LOW= B->A (OUTPUT 3.3V TO 5V)
#define DIR2_PIN  6 //GPIO2_10 - TO PIN 1 LVC245, HIGH= A->B (INPUT 5V TO 3.3V) LOW= B->A (OUTPUT 3.3V TO 5V)
#define BT2_PIN  35 //GPIO2_26
#define BT1_PIN  36 //GPIO2_28
#define BT3_PIN  34 //GPIO2_29
#define Status_PIN   37 //GPIO2_19
#define RST_PIN   7 //GPIO2_17
#define MSYNC_PIN   8 //GPIO2_16

// Inty bus values (BC2+BC1+BDIR)
#define BUS_NACT  0b000  //0
#define BUS_ADAR  0b010  //2
#define BUS_IAB   0b100  //4
#define BUS_DTB   0b110  //6
#define BUS_BAR   0b001  //1
#define BUS_DW    0b011  //3
#define BUS_DWS   0b101  //5
#define BUS_INTAK 0b111  //7

unsigned char busLookup[8];

#define BUS_STATE_MASK  0x00000070L // gpio9_4.5.6 pins 5.6.7
#define BUS_DIR_MASK 0x00000100L // gpio9_8 pin 9


char RBLo,RBHi;
constexpr size_t ROM_WORD_CAPACITY = 224000;
constexpr size_t RAM_WORD_CAPACITY = 8192;
constexpr size_t MAX_HACKS = 32;
uint16_t ROM[ROM_WORD_CAPACITY] DMAMEM;
uint16_t RAM[RAM_WORD_CAPACITY] DMAMEM;
uint16_t HACK[MAX_HACKS];
uint16_t HACK_CODE[MAX_HACKS];

unsigned int romLen;

unsigned int ramfrom = 0;
unsigned int ramto =   0;
unsigned int mapfrom[80];
unsigned int mapto[80];
unsigned int maprom[80];
unsigned int addrto[80];
unsigned int RAMused = 0;

unsigned int tipo[80];  // 0-rom / 1-page / 2-ram
unsigned int page[80];  // page number
int slot;
int hacks;

uint32_t selectedfile_size;       // BIN file size
char longfilename[46]{};      // long file name (truncated)
char mapfilename[64]{};       // matching CFG filename
int lenfilename = 0;
char path[96]{};

[[noreturn]] void haltWithMessage(const char* firstLine, const char* secondLine = nullptr) {
  display.clearDisplay();
  display.setTextSize(1);
  display.setTextColor(SSD1306_WHITE);
  display.setCursor(0, 1);
  display.print(firstLine);
  if (secondLine != nullptr) {
    display.setCursor(0, 16);
    display.print(secondLine);
  }
  display.display();
  while (true) {
    delay(1000);
  }
}

/////////////////////////////////////////////////////////////////////
//                   SelectBinFile()                               //
/////////////////////////////////////////////////////////////////////


void SelectBinFile() // adapted from the SDLEP-TFT project  http://dcmoto.free.fr/
{
  int i;
  int rootpos[255];
  int curpos=0;
  int lastpos;

  char suf[10];                 // extension file
  uint64_t file_size;        // tailles des fichiers affiches
  // Initialisations
  selectedfile_size = 0;          // initialisation de la taille du fichier choisi
  file_size = 0;
  bool selected = false;
  bool filefound = false;
  int subfolder = 0;    // nexting subfolders counter
  int dot = 0;

      display.clearDisplay();
      display.setTextSize(1);
      display.setTextColor(1);
      display.setCursor(0, 1);
      display.print("Reading card..");
      display.display();
      //delay(1000);

    // Boucle de choix du fichier
   path[0]=0;
   if (!(root=sd.open("/"))) {
    Serial.println("Error opening Root");
   }
   // wait all buttons are released
  while(digitalReadFast(BT1_PIN)|digitalReadFast(BT2_PIN)|digitalReadFast(BT3_PIN))
  while (!selected)
  {
     while (!filefound)
    {
        //read next file
        lastpos=root.curPosition();
        entry=root.openNextFile();

      if(!entry)
      {
        if (subfolder>0) {
          strcpy(longfilename,"..");
        root.rewindDirectory();
         break;
        } else {
        root.rewindDirectory();
        lastpos=root.curPosition();
        entry=root.openNextFile();
        entry.getName(longfilename,45);
        break;
        }
      //entry.close();
        continue;
      }

        if(entry.isDirectory()) {   //handling subdirectory
          entry.getName(longfilename,45);
          if (strcmp(longfilename,"System Volume Information")==0) {
           continue;
         } else {
           filefound=true;
           break;
         }
        }

      for(i=0; i<46; i++) longfilename[i]=0;
      entry.getName(longfilename,45);
      dot=0;
      for(i=0; i<43; i++) {
        if (longfilename[i]=='.') {
          dot=i;
        }
      }
      if(dot==0)
      {
        continue; //dot not found, get next file
      }
      suf[0]=0;
      //test du suffixe
      suf[0]=longfilename[dot+1];
      suf[1]=longfilename[dot+2];
      suf[2]=longfilename[dot+3];
      suf[3]=0;

      if(strcmp(suf,"bin")!=0  && strcmp(suf,"BIN")!=0 )
        continue; //not BIN file
      filefound=true;
    }

     // .bin found
     // save position
        rootpos[curpos]=lastpos;
        curpos++;

      file_size = entry.size();
      int kb=(file_size >>10);
      display.clearDisplay();
      display.setTextSize(1);
      display.setTextColor(1);
      display.setCursor(0, 1);
      display.print(longfilename);
      display.setCursor(0,24);
      if (entry.isDirectory()) {
        display.print("DIR");
      } else
      { display.print("KB:");
      display.setCursor(22,24);
      display.print(kb,DEC);
      }
      display.display();

    filefound=false;


    //check user button and time
    while (1)
    {
      //Next button
      if (digitalRead(BT1_PIN)) {
          digitalWriteFast(Status_PIN,HIGH);
          delay(300);
          digitalWriteFast(Status_PIN,LOW);
          break; // readnext file
       }

      //Prev button
      if (digitalRead(BT3_PIN)) {
          digitalWriteFast(Status_PIN,HIGH);
          delay(300);
          digitalWriteFast(Status_PIN,LOW);
          if (curpos>1) {
            curpos-=2;
          } else {
            curpos=0;
          }
          root.seekSet(rootpos[curpos]);
          break;
      }
      //SELECT Button
      if (digitalRead(BT2_PIN)) {
          digitalWriteFast(Status_PIN,HIGH);
          delay(300);
          digitalWriteFast(Status_PIN,LOW);
          if (entry.isDirectory()) {
            root=sd.open(longfilename);
            strcat(path,longfilename);
            subfolder++;
            break;
          } else
          if (strcmp(longfilename,"..")==0) {
            root=sd.open("/");
            for(i=0;i<50;i++) path[i]=0;
            subfolder--;
            break;
          } else {
          selected=true;
          break; // readnext file
          }
        }
      }
    } //fin de la boucle de choix du fichier (on en sort si le fichier a ete choisi)
  //root.close();  //fermeture du repertoire de la carte SD
  //return file_return;
}

////////////////////////////////////////////////////////////////////////////////////
//                     LOAD ROM
////////////////////////////////////////////////////////////////////////////////////

void loadROM() {


  String riga;
  char tmphex[] {0,0,0,0,0,0};
  int linepos;


  for(int i=0; i<45; i++) {
        if (longfilename[i]=='.') {
          lenfilename= i;  //dot found
        }
  }

  memcpy(mapfilename,longfilename,lenfilename);
  strcat(mapfilename,".cfg");

  strcat(path,"/");
  strcat(path,mapfilename);
  mapfile=sd.open(path);
  //  mapfile=SD.open(mapfilename);
  if (!mapfile) {
    mapfile.openNextFile();
    mapfile=sd.open("0.cfg");
    }
  if (!mapfile) {
    display.clearDisplay();
    display.setCursor(0, 1);
    display.print("Map CFG file error");
    display.setCursor(0,16);
    display.print("restart RTO");
    display.display();
    while(1);
  }

  slot=0;
  hacks=0;

  while (mapfile.available()) {
    riga=mapfile.readStringUntil('\n');
    if (riga.length()>1) {
      String tmp=riga.substring(0,9);
      if (slot==0) {
        if (tmp=="[mapping]") {
          riga=mapfile.readStringUntil('\n');
        } else {
          display.clearDisplay();
          display.setCursor(0, 1);
          display.print("[mapping] not found");
          display.display();
          while(1);
        }
      }

      if (tmp=="[memattr]") {
        riga=mapfile.readStringUntil('\n');
        Serial.println("Memattr");
        tmp=riga.substring(1,5);
        tmp.toCharArray(tmphex,5);
        ramfrom=strtoul(tmphex,NULL,16);
        mapfrom[slot]=ramfrom;
        tmp=riga.substring(9,13);
        tmp.toCharArray(tmphex,5);
        ramto=strtoul(tmphex,NULL,16);
        mapto[slot]=ramto;
        maprom[slot]=ramfrom;
        addrto[slot]=maprom[slot]+(mapto[slot]-mapfrom[slot]);
        tipo[slot]=2; // RAM
        RAMused=1;
        slot++;
      } else {
        tmp=riga.substring(0,1);
        if (tmp=="p") {
          // [MACRO]
          tmp=riga.substring(2,6);
          tmp.toCharArray(tmphex,6);
          HACK[hacks]=strtoul(tmphex,NULL,16);
          tmp=riga.substring(7,10);
          tmp.toCharArray(tmphex,4);
          HACK_CODE[hacks]=strtoul(tmphex,NULL,16);
          Serial.print(HACK[hacks],HEX);Serial.print("-");
          Serial.println(HACK_CODE[hacks],HEX);
          hacks++;
        } else {
        //mapping
        linepos=riga.indexOf("-");
        if (linepos>=0) {
          tmp=riga.substring(1,linepos-1);
          tmp.toCharArray(tmphex,6);
          mapfrom[slot]=strtoul(tmphex,NULL,16);
          tmp=riga.substring(linepos+3,linepos+9);
          tmp.toCharArray(tmphex,6);
          mapto[slot]=strtoul(tmphex,NULL,16);
          if (linepos==6) {
            tmp=riga.substring(linepos+11,linepos+15);
          } else {
            tmp=riga.substring(linepos+12,linepos+17);
          }
          tmp.toCharArray(tmphex,6);
          maprom[slot]=strtoul(tmphex,NULL,16);
          if (linepos==6) {
            tmp=riga.substring(22,26);
          } else {
            tmp=riga.substring(24,28);
          }
          tmp.toCharArray(tmphex,6);
          addrto[slot]=maprom[slot]+(mapto[slot]-mapfrom[slot]);
          if (!(strcmp(tmphex,"PAGE"))) {
            tipo[slot]=1;
            if (linepos==6) {
              tmp=riga.substring(27,28);
            } else {
              tmp=riga.substring(29,31);
            }
          tmp.toCharArray(tmphex,2);
          page[slot]=strtoul(tmphex,NULL,16);
          } else {
            tipo[slot]=0;
          }
          slot++;
          }
        }
        Serial.print("Slot:");Serial.print(slot-1);
        Serial.print("-From:");Serial.print(mapfrom[slot-1],HEX);
        Serial.print(" to:");Serial.print(mapto[slot-1],HEX);
        Serial.print(" IN:");Serial.print(maprom[slot-1],HEX);
        Serial.print(" tipo:");Serial.print(tipo[slot-1]);
        Serial.print(" page:");Serial.print(page[slot-1]);
        Serial.print(" addr-to:");Serial.println(addrto[slot-1],HEX);
        }
     }
  }

  slot--;  // conservo il numero di slot!
  Serial.print("Slots:");Serial.println(slot);
  if (entry) {
    // read from the file until there's nothing else in it:
    romLen=0;
    while (entry.available()) {
      RBHi = entry.read();
      RBLo = entry.read();
      unsigned int dataW= RBLo | (RBHi << 8);
      //fileOffset=romLen - mapfrom[slot] + maprom[slot];
      ROM[romLen]=dataW;
      romLen++;
         if (romLen>BINLENGTH) {
          display.clearDisplay();
          display.setCursor(0, 1);
          display.print("File too big!");
          display.setCursor(0,16);
          display.print(longfilename);
          display.display();
          while(1);
      }

    }
    //verify
  //  slot=0;
    romLen=0;
    entry.seek(0);
    while (entry.available()) {
      RBHi=entry.read();
      RBLo=entry.read();
      unsigned int dataW= RBLo | (RBHi << 8);
      //fileOffset=romLen - mapfrom[slot] + maprom[slot];
      if (ROM[romLen]!= dataW) {
        display.clearDisplay();
        display.setCursor(0, 1);
        display.print("Verify file error!");
        display.display();
        while(1);
      }
      romLen++;
     }
    // close the file:
    entry.close();
  } else {
    // if the file didn't open, print an error:
    display.clearDisplay();
    display.setCursor(0, 1);
    display.print("Error opening file:");
    display.setCursor(0,16);
    display.print(longfilename);
    display.display();
    return;
     }
  if (hacks>0) {
    display.clearDisplay();
    display.setCursor(0, 1);
    display.print("Hack found: use it?");
    display.setCursor(0,16);
    display.print("OK to confirm, Next or Prev to deny");
    display.display();
    delay(500); // wait to clear buttons
    while(((digitalReadFast(BT1_PIN)==0) & (digitalReadFast(BT2_PIN)==0) & (digitalReadFast(BT3_PIN)==0))) {
      if ((digitalReadFast(BT1_PIN)==1) | (digitalReadFast(BT3_PIN)==1)) hacks=0;
    }
  }
}

////////////////////////////////////////////////////////////////////////////////////
//                     SETUP
////////////////////////////////////////////////////////////////////////////////////
void setup() {

  long MUX = 21;
  IOMUXC_SW_MUX_CTL_PAD_GPIO_AD_B1_00 = MUX;
  IOMUXC_SW_MUX_CTL_PAD_GPIO_AD_B1_01 = MUX;
  IOMUXC_SW_MUX_CTL_PAD_GPIO_AD_B1_02 = MUX;
  IOMUXC_SW_MUX_CTL_PAD_GPIO_AD_B1_03 = MUX;
  IOMUXC_SW_MUX_CTL_PAD_GPIO_AD_B1_04 = MUX;
  IOMUXC_SW_MUX_CTL_PAD_GPIO_AD_B1_05 = MUX;
  IOMUXC_SW_MUX_CTL_PAD_GPIO_AD_B1_06 = MUX;
  IOMUXC_SW_MUX_CTL_PAD_GPIO_AD_B1_07 = MUX;
  IOMUXC_SW_MUX_CTL_PAD_GPIO_AD_B1_08 = MUX;
  IOMUXC_SW_MUX_CTL_PAD_GPIO_AD_B1_09 = MUX;
  IOMUXC_SW_MUX_CTL_PAD_GPIO_AD_B1_10 = MUX;
  IOMUXC_SW_MUX_CTL_PAD_GPIO_AD_B1_11 = MUX;
  IOMUXC_SW_MUX_CTL_PAD_GPIO_AD_B1_12 = MUX;
  IOMUXC_SW_MUX_CTL_PAD_GPIO_AD_B1_13 = MUX;
  IOMUXC_SW_MUX_CTL_PAD_GPIO_AD_B1_14 = MUX;
  IOMUXC_SW_MUX_CTL_PAD_GPIO_AD_B1_15 = MUX;

  IOMUXC_SW_MUX_CTL_PAD_GPIO_EMC_04 = MUX; //GPIO4_4  BDIR
  IOMUXC_SW_MUX_CTL_PAD_GPIO_EMC_05 = MUX; //GPIO4_5  BC1
  IOMUXC_SW_MUX_CTL_PAD_GPIO_EMC_06 = MUX; //GPIO4_6  BC2

  long PAD = 0B00000000000000010011000000111000;
  //           |||||||||||||||||||||||||||||||+-FAST
  //           |||||||||||||||||||||||||||||++--RESERVED
  //           ||||||||||||||||||||||||||+++----DSE
  //           ||||||||||||||||||||||||++-------SPEED
  //           |||||||||||||||||||||+++---------RESERVED
  //           ||||||||||||||||||||+------------ODE (OPEN DRAIN)
  //           |||||||||||||||||||+-------------PKE
  //           ||||||||||||||||||+--------------PUE
  //           ||||||||||||||||++---------------PUS
  //           |||||||||||||||+-----------------HYS
  //           ++++++++++++++++-----------------RESERVED
  IOMUXC_SW_PAD_CTL_PAD_GPIO_AD_B1_00 = PAD;
  IOMUXC_SW_PAD_CTL_PAD_GPIO_AD_B1_01 = PAD;
  IOMUXC_SW_PAD_CTL_PAD_GPIO_AD_B1_02 = PAD;
  IOMUXC_SW_PAD_CTL_PAD_GPIO_AD_B1_03 = PAD;
  IOMUXC_SW_PAD_CTL_PAD_GPIO_AD_B1_04 = PAD;
  IOMUXC_SW_PAD_CTL_PAD_GPIO_AD_B1_05 = PAD;
  IOMUXC_SW_PAD_CTL_PAD_GPIO_AD_B1_06 = PAD;
  IOMUXC_SW_PAD_CTL_PAD_GPIO_AD_B1_07 = PAD;
  IOMUXC_SW_PAD_CTL_PAD_GPIO_AD_B1_08 = PAD;
  IOMUXC_SW_PAD_CTL_PAD_GPIO_AD_B1_09 = PAD;
  IOMUXC_SW_PAD_CTL_PAD_GPIO_AD_B1_10 = PAD;
  IOMUXC_SW_PAD_CTL_PAD_GPIO_AD_B1_11 = PAD;
  IOMUXC_SW_PAD_CTL_PAD_GPIO_AD_B1_12 = PAD;
  IOMUXC_SW_PAD_CTL_PAD_GPIO_AD_B1_13 = PAD;
  IOMUXC_SW_PAD_CTL_PAD_GPIO_AD_B1_14 = PAD;
  IOMUXC_SW_PAD_CTL_PAD_GPIO_AD_B1_15 = PAD;

  IOMUXC_SW_PAD_CTL_PAD_GPIO_EMC_04 = PAD;
  IOMUXC_SW_PAD_CTL_PAD_GPIO_EMC_05 = PAD;
  IOMUXC_SW_PAD_CTL_PAD_GPIO_EMC_06 = PAD;

 // Initialize the bus state variables

  busLookup[BUS_NACT]  = 4; // 100
  busLookup[BUS_BAR]   = 1; // 001
  busLookup[BUS_IAB]   = 4; // 100
  busLookup[BUS_DWS]   = 2; // 010   // test without dws handling
  busLookup[BUS_ADAR]  = 1; // 001
  busLookup[BUS_DW]    = 4; // 100
  busLookup[BUS_DTB]   = 0; // 000
  busLookup[BUS_INTAK] = 4; // 100

//  IOMUXC_GPR_GPR26 &=0xffff0000; not needed in teensy 4.1, it's default

 //Serial.begin(115200);

  pinMode(Status_PIN, OUTPUT);
  pinMode(BT1_PIN,INPUT_PULLDOWN);
  pinMode(BT2_PIN,INPUT_PULLDOWN);
  pinMode(BT3_PIN,INPUT_PULLDOWN);
  pinMode(DIR2_PIN,OUTPUT);
  pinMode(RST_PIN,OUTPUT);
  pinMode(MSYNC_PIN,INPUT_PULLDOWN);

  digitalWriteFast(RST_PIN,LOW);   //???????????
  digitalWriteFast(DIR2_PIN,HIGH); // A->B, TEENSY to INTV BUS

  for (long i=0; i<BINLENGTH; i++) {
    ROM[i]=0;
  }

 for (long i=0; i<RAMSIZE; i++) {
    RAM[i]=0;
  }

 for (int i=0; i<maxHacks; i++) {
  HACK[i]=0;
  HACK_CODE[i]=0;
 }

  while (!display.begin(SSD1306_SWITCHCAPVCC, SCREEN_ADDRESS));
  display.clearDisplay();
  display.setTextSize(2);
  display.setTextColor(1);

  display.setCursor(12, 1);
  display.print("RTO Cart");
  display.setTextSize(1);
  display.setCursor(110,22);
  display.print("1.0");
  display.display();
  //delay(500); // Pause for 2 seconds

  while (!sd.begin(SD_CONFIG))
  {
    display.clearDisplay();
    display.setCursor(0, 1);
    display.print("Insert SDCard");
    display.display();
  //  delay(1000);
  }

  for(int i=0;i<1280;i++){
    unsigned int dataW= splash[(i*2)+1] | (splash[i*2] << 8);
    ROM[i]=dataW;
  }
  slot=0;
  mapfrom[0]=0x0;
  mapto[0]=0x4ff;
  maprom[0]=0x5000;
  tipo[0]=0;
  page[0]=0;
  addrto[0]=0x54ff;

  display.clearDisplay();
  display.setCursor(0, 1);
  display.print("Press a button on RTO");
  display.display();
  resetCart();
  HandleBUS();

  Serial.println("exit splash");
  SelectBinFile();
  loadROM();
  display.clearDisplay();
  display.setCursor(0, 1);
  display.print("Emulating ROM:");
  display.setCursor(0,16);
  display.print(longfilename);
  if (hacks>0) {
    display.setCursor(92,1);
    display.setTextSize(1.5);
    display.print("(H)");
  }
  display.display();


}

void yield () {} //Get rid of the hidden function that checks for serial input and such.

void doReboot() {
  SCB_AIRCR = 0x05FA0004;
}

////////////////////////////////////////////////////////////////////////////////////
//                     RESET
////////////////////////////////////////////////////////////////////////////////////
void resetCart() {

  digitalWriteFast(Status_PIN,HIGH);
  Serial.println(digitalReadFast(MSYNC_PIN));

  do {
    digitalWriteFast(Status_PIN,digitalReadFast(MSYNC_PIN));
    digitalWriteFast(RST_PIN,HIGH);
    delay(6);
    if (digitalReadFast(MSYNC_PIN)==0) break;
    digitalWriteFast(RST_PIN,LOW);
    delay(2);
    if (digitalReadFast(MSYNC_PIN)==0) break;

  } while (digitalReadFast(MSYNC_PIN)==1);

//  do {
   digitalWriteFast(Status_PIN,digitalReadFast(MSYNC_PIN));
   digitalWriteFast(RST_PIN,LOW);
 // } while (digitalReadFast(MSYNC_PIN)==0);


  Serial.println(digitalReadFast(MSYNC_PIN));

  digitalWriteFast(Status_PIN,LOW);
   //pinMode(RST_PIN,INPUT);
  //Serial.println("Reset");
}

////////////////////////////////////////////////////////////////////////////////////
//                     HANDLE BUS
////////////////////////////////////////////////////////////////////////////////////
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
void loop()
{
resetCart();
HandleBUS();
}

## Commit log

2026-10-05 Initial version
    [intellicart-B_Cu.gbl, intellicart-B_Mask.gbs, intellicart-B_Paste.gbp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]
2026-10-05 Rebrand Intellicart project and add Checkers analysis
    [intellicart-B_Cu.gbl, intellicart-B_Mask.gbs, intellicart-B_Paste.gbp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]
2026-10-05 Add Intellicart assembly guide and Teensy firmware
2026-10-22 Make board profile standalone
2026-10-22 Prefer additional card-edge insertion clearance
2026-11-11 Add Checkers board geometry fixtures
2026-11-11 Validate Checkers board mailbox requests
2026-11-11 Frame bounded intuition contribution
